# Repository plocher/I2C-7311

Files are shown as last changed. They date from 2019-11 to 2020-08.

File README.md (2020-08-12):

# I2C-7311
## License: CERN Open Hardware Licence v1.2

IO Expander with 4x IO4 connections

### Introduction

This board was originally produced to help me build control panels for
my model railroad - I needed to connect many different buttons, switches
and lights to an Arduino, and also connect the Arduino to a
communications bus (Ethernet, CAN or Loconet), and I couldn\'t find
anything that had both high IO point density AND visual feedback.

I started with a simple I2C based 32-pin Arduino
[IOShield](/pages/IOShield "wikilink") with monitoring LEDs on each pin
(Active-LOW inputs, LED is on when pin is grounded, writing a \"1\" to
the port pulls it to ground). I was aiming to support up to the max I2C
devices that can be used together, with the 8-bit board
[I2C-8574-IO](/pages/I2C-8574-IO "wikilink") (deprecated), that was a total of
8x boards with 128 i/o points.

The 7311 IO expanders used here will support up to 64 boards, with 1024
potential I/O points.

This latest design moves from overly generic and/or overly specialized
designs to a generic design with daughterboards that encapsulate the
appliance-specific buffering and logic. The benefits provided by these
IOB boards include:

-   Improved I/O bank utilization (leftover capacity is now a multiple
    of 4-bit daughtercard instead of 16-bit I2C card\...)
-   Riser height eliminates having to custom cut 3M track
-   Allows deprecation of cabling intensive signal driver IO4 and I2C
    boards
-   Allows custom circuitry to be added to Signal, Detector and Turtle
    drivers

### Cautions

With several hundred IO loads, and up to 256 external breakout devices,
a suitable power supply (or supplies) must be used.

In practice, a 3A 9-12VDC supply a good choice for most small to medium
sized control points.

This supply needs to power the core processor, its direct IO loads, the
I2C expander chain AND provide \~100mA to each IO4 device. Instead of
relying on the Arduino\'s onboard regulated supply (which is only good
for about 100mA itself), each board has its own regulator with a common
supply feed that can handle up to 4A @ 12v. If more power is needed, the
daisy chained power feed thru can be replaced with a per-board
independent supply.

### Specifications

This IO board is based on the MAX7311/12 16 bit IO Expander, with a a
bank of 4x I/O Boards. These IOBs contain buffered LED drivers connected
to LEDs that show the status of the I/O lines in real time. They also
contain the needed circuitry to drive / sense the appliances connected
to them. See

-   [IOB-Inputs](/pages/IOB-Inputs "wikilink") 4x buffered inputs
-   [IOB-Outputs](/pages/IOB-Outputs "wikilink") 4x buffered outputs
-   [IOB-Turtle](/pages/IOB-Turtle "wikilink") 1x buffered output and 3x buffered inputs
-   [IOB-Signal](/pages/IOB-Signal "wikilink") 2x RGB signal head driver (Dark, Stop, Approach, Clear)

Each board provides a latched set of 16x IO points, with each point
being software selectable to be either an input or an output. The
individual points are reasonably protected from the environment, and can
sink 10 mA each (with the MAX7312, they can also drive \~20mA). By using
active low inputs and outputs, the effects of environmental noise are
reduced - remote sensors only need to ground an I/O point to register
activity.

#### Communication Protocol {#communication_protocol}

``` {.cpp}
Simple I2C 16-bit Reads and Writes:
uint16_t I2Cexpander::read7311() {
    uint16_t data = 0;
    Wire.beginTransmission(_i2c_address);
    Wire.write(REGISTER_7311INPUT);
    Wire.endTransmission();
    // Wire.beginTransmission(_i2c_address);
    Wire.requestFrom(_i2c_address, (uint8_t)2);
    if(Wire.available()) {
        data = Wire.read();
    }
    if(Wire.available()) {
        data |= (Wire.read() << 8);
    }
    // Wire.endTransmission();
    return data;
}

void I2Cexpander::write7311(uint16_t data) {
    data = data | _config;
    Wire.beginTransmission(_i2c_address);
    Wire.write(REGISTER_7311OUTPUT);
    Wire.write(0xff & data);  //  low byte
    Wire.write(data >> 8);    //  high byte
    Wire.endTransmission();
}
```

See [I2Cexpander-lib](/pages/I2Cexpander "wikilink") for a more complete interface
library.

#### Addressing

**AD2**|**AD1**|**AD0**|**A6**|**A5**|**A4**|**A3**|**A2**|**A1**|**A0**|**ADDRESS (HEX)**
:-----:|:-----:|:-----:|:-----:|:-----:|:-----:|:-----:|:-----:|:-----:|:-----:|:-----:
GND|SCL|GND|0|0|1|0|0|0|0|0x20
GND|SCL|V+|0|0|1|0|0|0|1|0x22
GND|SDA|GND|0|0|1|0|0|1|0|0x24
GND|SDA|V+|0|0|1|0|0|1|1|0x26
V+|SCL|GND|0|0|1|0|1|0|0|0x28
V+|SCL|V+|0|0|1|0|1|0|1|0x2A
V+|SDA|GND|0|0|1|0|1|1|0|0x2C
V+|SDA|V+|0|0|1|0|1|1|1|0x2E
GND|SCL|SCL|0|0|1|1|0|0|0|0x30
GND|SCL|SDA|0|0|1|1|0|0|1|0x32
GND|SDA|SCL|0|0|1|1|0|1|0|0x34
GND|SDA|SDA|0|0|1|1|0|1|1|0x36
V+|SCL|SCL|0|0|1|1|1|0|0|0x38
V+|SCL|SDA|0|0|1|1|1|0|1|0x3A
V+|SDA|SCL|0|0|1|1|1|1|0|0x3C
V+|SDA|SDA|0|0|1|1|1|1|1|0x3E
GND|GND|GND|0|1|0|0|0|0|0|0x40
GND|GND|V+|0|1|0|0|0|0|1|0x42
GND|V+|GND|0|1|0|0|0|1|0|0x44
GND|V+|V+|0|1|0|0|0|1|1|0x46
V+|GND|GND|0|1|0|0|1|0|0|0x48
V+|GND|V+|0|1|0|0|1|0|1|0x4A
V+|V+|GND|0|1|0|0|1|1|0|0x4C
V+|V+|V+|0|1|0|0|1|1|1|0x4E
GND|GND|SCL|0|1|0|1|0|0|0|0x50
GND|GND|SDA|0|1|0|1|0|0|1|0x52
GND|V+|SCL|0|1|0|1|0|1|0|0x54
GND|V+|SDA|0|1|0|1|0|1|1|0x56
V+|GND|SCL|0|1|0|1|1|0|0|0x58
V+|GND|SDA|0|1|0|1|1|0|1|0x5A
V+|V+|SCL|0|1|0|1|1|1|0|0x5C
V+|V+|SDA|0|1|0|1|1|1|1|0x5E
SCL|SCL|GND|1|0|1|0|0|0|0|0xA0
SCL|SCL|V+|1|0|1|0|0|0|1|0xA2
SCL|SDA|GND|1|0|1|0|0|1|0|0xA4
SCL|SDA|V+|1|0|1|0|0|1|1|0xA6
SDA|SCL|GND|1|0|1|0|1|0|0|0xA8
SDA|SCL|V+|1|0|1|0|1|0|1|0xAA
SDA|SDA|GND|1|0|1|0|1|1|0|0xAC
SDA|SDA|V+|1|0|1|0|1|1|1|0xAE
SCL|SCL|SCL|1|0|1|1|0|0|0|0xB0
SCL|SCL|SDA|1|0|1|1|0|0|1|0xB2
SCL|SDA|SCL|1|0|1|1|0|1|0|0xB4
SCL|SDA|SDA|1|0|1|1|0|1|1|0xB6
SDA|SCL|SCL|1|0|1|1|1|0|0|0xB8
SDA|SCL|SDA|1|0|1|1|1|0|1|0xBA
SDA|SDA|SCL|1|0|1|1|1|1|0|0xBC
SDA|SDA|SDA|1|0|1|1|1|1|1|0xBE
SCL|GND|GND|1|1|0|0|0|0|0|0xC0
SCL|GND|V+|1|1|0|0|0|0|1|0xC2
SCL|V+|GND|1|1|0|0|0|1|0|0xC4
SCL|V+|V+|1|1|0|0|0|1|1|0xC6
SDA|GND|GND|1|1|0|0|1|0|0|0xC8
SDA|GND|V+|1|1|0|0|1|0|1|0xCA
SDA|V+|GND|1|1|0|0|1|1|0|0xCC
SDA|V+|V+|1|1|0|0|1|1|1|0xCE
SCL|GND|SCL|1|1|0|1|0|0|0|0xD0
SCL|GND|SDA|1|1|0|1|0|0|1|0xD2
SCL|V+|SCL|1|1|0|1|0|1|0|0xD4
SCL|V+|SDA|1|1|0|1|0|1|1|0xD6
SDA|GND|SCL|1|1|0|1|1|0|0|0xD8
SDA|GND|SDA|1|1|0|1|1|0|1|0xDA
SDA|V+|SCL|1|1|0|1|1|1|0|0xDC
SDA|V+|SDA|1|1|0|1|1|1|1|0xDE

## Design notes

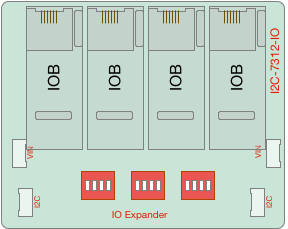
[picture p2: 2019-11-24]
I2C-7311-Graphic.png

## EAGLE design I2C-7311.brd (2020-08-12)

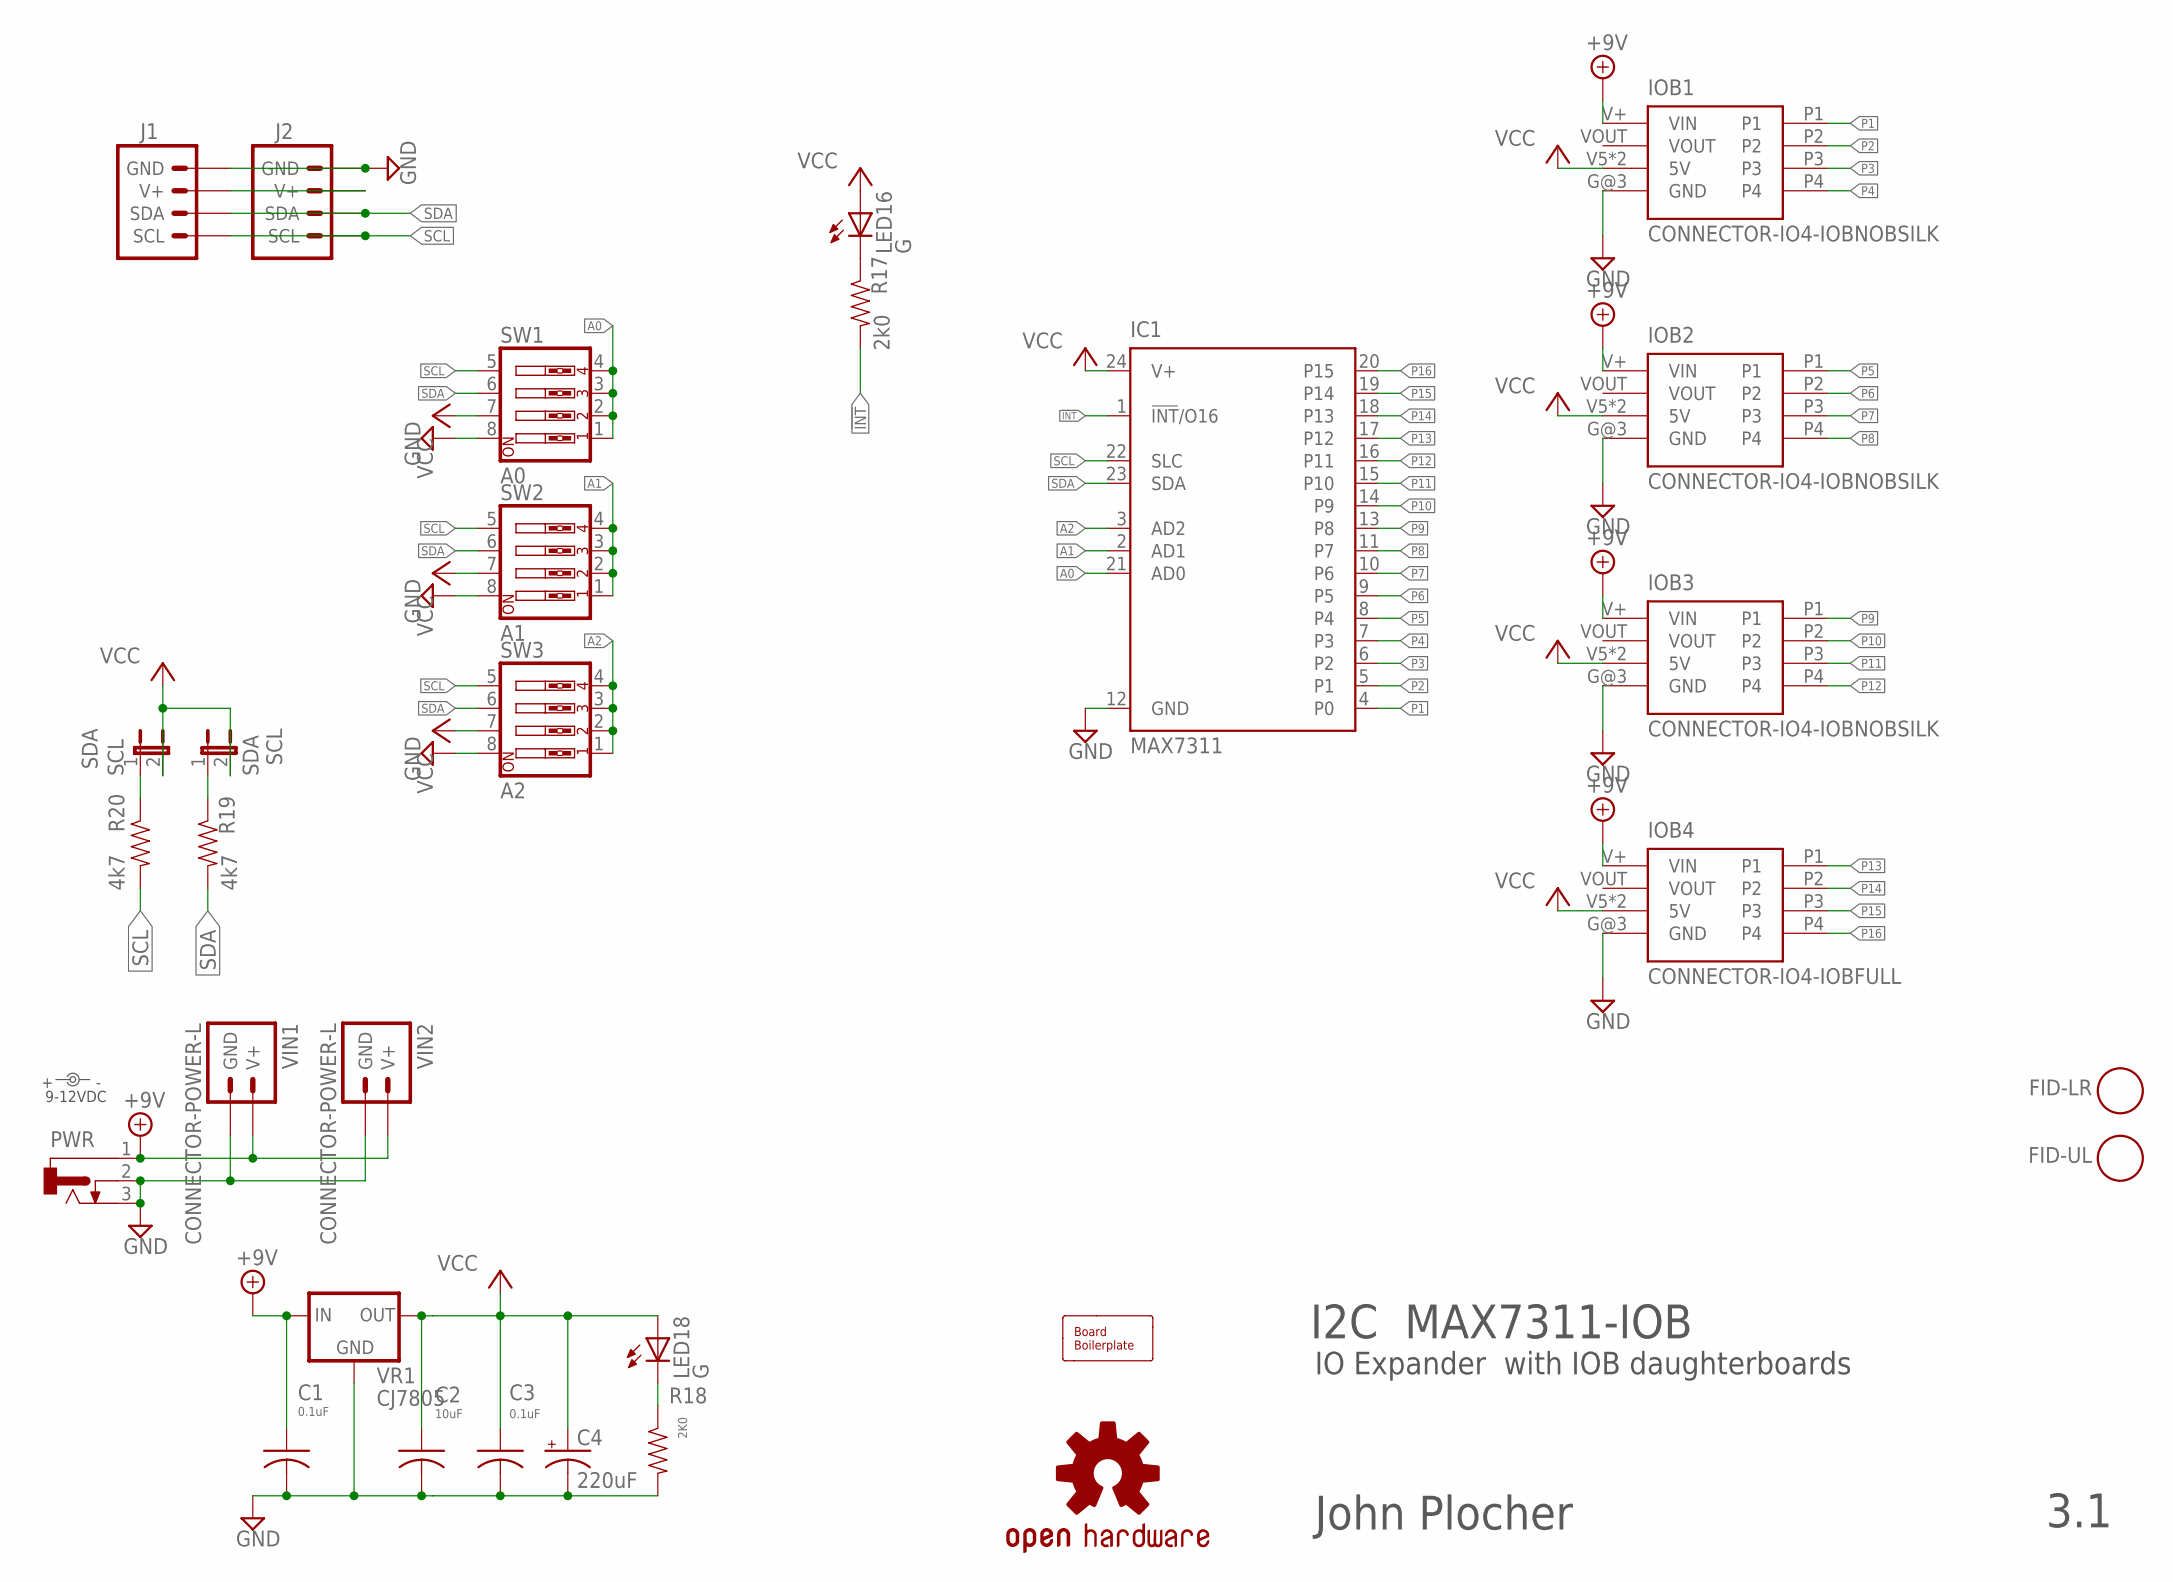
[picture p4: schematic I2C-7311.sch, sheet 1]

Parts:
BOARD1: BOARD80X100-IOB; BOARD-DINRAIL-3.17IN-IOB
C1, C3: 0.1uF; 0805-CAP
C2: 10uF; 0805-CAP
C4: 220uF; 0810-CAP
FID-LR: FIDUCIAL; FIDUCIAL_1MM
FID-UL: FIDUCIAL; FIDUCIAL_1MM
IC1: MAX7311; TSSOP24
IOB1, IOB2, IOB3: CONNECTOR-IO4-IOBNOBSILK; IOB-IO4-NOBOTSILK
IOB4: CONNECTOR-IO4-IOBFULL; IO4-IOB
J1, J2: CONNECTOR-I2CLEFT; I2C-L
LED16, LED18: G; 0603-LED
PWR: CONNECTOR-DC-POWER-RA; DCJ0202
R17: 2k0; 0805-RES
R18: 2K0; 0805-RES
R19, R20: 4k7; 0805-RES
SCL: SDA; 1X02_LOCK
SDA: SCL; 1X02_LOCK
SW1: A0; EDG-04
SW2: A1; EDG-04
SW3: A2; EDG-04
U$1: OSHW-LOGOL; OSHW-LOGO-L
VIN: 9-12VDC; PWR_LABEL
VIN1, VIN2: CONNECTOR-POWER-L; POWER-R2
VR1: CJ7805; TO-252

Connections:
!INT: IC1.1 (!INT!/O16), R17.2
+9V: C1.1, IOB1.V+ (VIN), IOB2.V+ (VIN), IOB3.V+ (VIN), IOB4.V+ (VIN), PWR.1, VIN1.V+, VIN1.V+@1 (V+), VIN1.V+@2 (V+), VIN1.V+@3 (V+), VIN2.V+, VIN2.V+@1 (V+), VIN2.V+@2 (V+), VIN2.V+@3 (V+), VR1.1 (IN)
A0: IC1.21 (AD0), SW1.1, SW1.2, SW1.3, SW1.4
A1: IC1.2 (AD1), SW2.1, SW2.2, SW2.3, SW2.4
A2: IC1.3 (AD2), SW3.1, SW3.2, SW3.3, SW3.4
GND: C1.2, C2.2, C3.2, C4.-, IC1.12 (GND), IOB1.G@3 (GND), IOB2.G@3 (GND), IOB3.G@3 (GND), IOB4.G@3 (GND), J1.GND, J1.GND@1 (GND), J2.GND, J2.GND@1 (GND), PWR.2, PWR.3, R18.2, SW1.8, SW2.8, SW3.8, VIN1.GND, VIN1.GND@1 (GND), VIN1.GND@2 (GND), VIN1.GND@3 (GND), VIN2.GND, VIN2.GND@1 (GND), VIN2.GND@2 (GND), VIN2.GND@3 (GND), VR1.2 (GND); also elsewhere on the board
unnamed: LED18.C, R18.1
unnamed: R19.1, SCL.1
unnamed: R20.1, SDA.1
unnamed: LED16.C, R17.1
P1: IC1.4 (P0), IOB1.P1; also elsewhere on the board
P2: IC1.5 (P1), IOB1.P2; also elsewhere on the board
P3: IC1.6 (P2), IOB1.P3; also elsewhere on the board
P4: IC1.7 (P3), IOB1.P4; also elsewhere on the board
P5: IC1.8 (P4), IOB2.P1; also elsewhere on the board
P6: IC1.9 (P5), IOB2.P2; also elsewhere on the board
P7: IC1.10 (P6), IOB2.P3; also elsewhere on the board
P8: IC1.11 (P7), IOB2.P4; also elsewhere on the board
P9: IC1.13 (P8), IOB3.P1; also elsewhere on the board
P10: IC1.14 (P9), IOB3.P2; also elsewhere on the board
P11: IC1.15 (P10), IOB3.P3; also elsewhere on the board
P12: IC1.16 (P11), IOB3.P4; also elsewhere on the board
P13: IC1.17 (P12), IOB4.P1; also elsewhere on the board
P14: IC1.18 (P13), IOB4.P2; also elsewhere on the board
P15: IC1.19 (P14), IOB4.P3; also elsewhere on the board
P16: IC1.20 (P15), IOB4.P4; also elsewhere on the board
SCL: IC1.22 (SLC), J1.SCL, J1.SCL@1 (SCL), J2.SCL, J2.SCL@1 (SCL), R20.2, SW1.5, SW2.5, SW3.5
SDA: IC1.23 (SDA), J1.SDA, J1.SDA@1 (SDA), J2.SDA, J2.SDA@1 (SDA), R19.2, SW1.6, SW2.6, SW3.6
V+I2C: J1.V+, J1.V+@1 (V+), J2.V+, J2.V+@1 (V+)
VCC: C2.1, C3.1, C4.+, IC1.24 (V+), IOB1.V5 (5V), IOB1.V5@1 (5V), IOB2.V5 (5V), IOB2.V5@1 (5V), IOB3.V5 (5V), IOB3.V5@1 (5V), IOB4.V5 (5V), IOB4.V5@1 (5V), LED16.A, LED18.A, SCL.2, SDA.2, SW1.7, SW2.7, SW3.7, VR1.3 (OUT); also elsewhere on the board

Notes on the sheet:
I2C MAX7311-IOB
IO Expander with IOB daughterboards
John Plocher
3.1

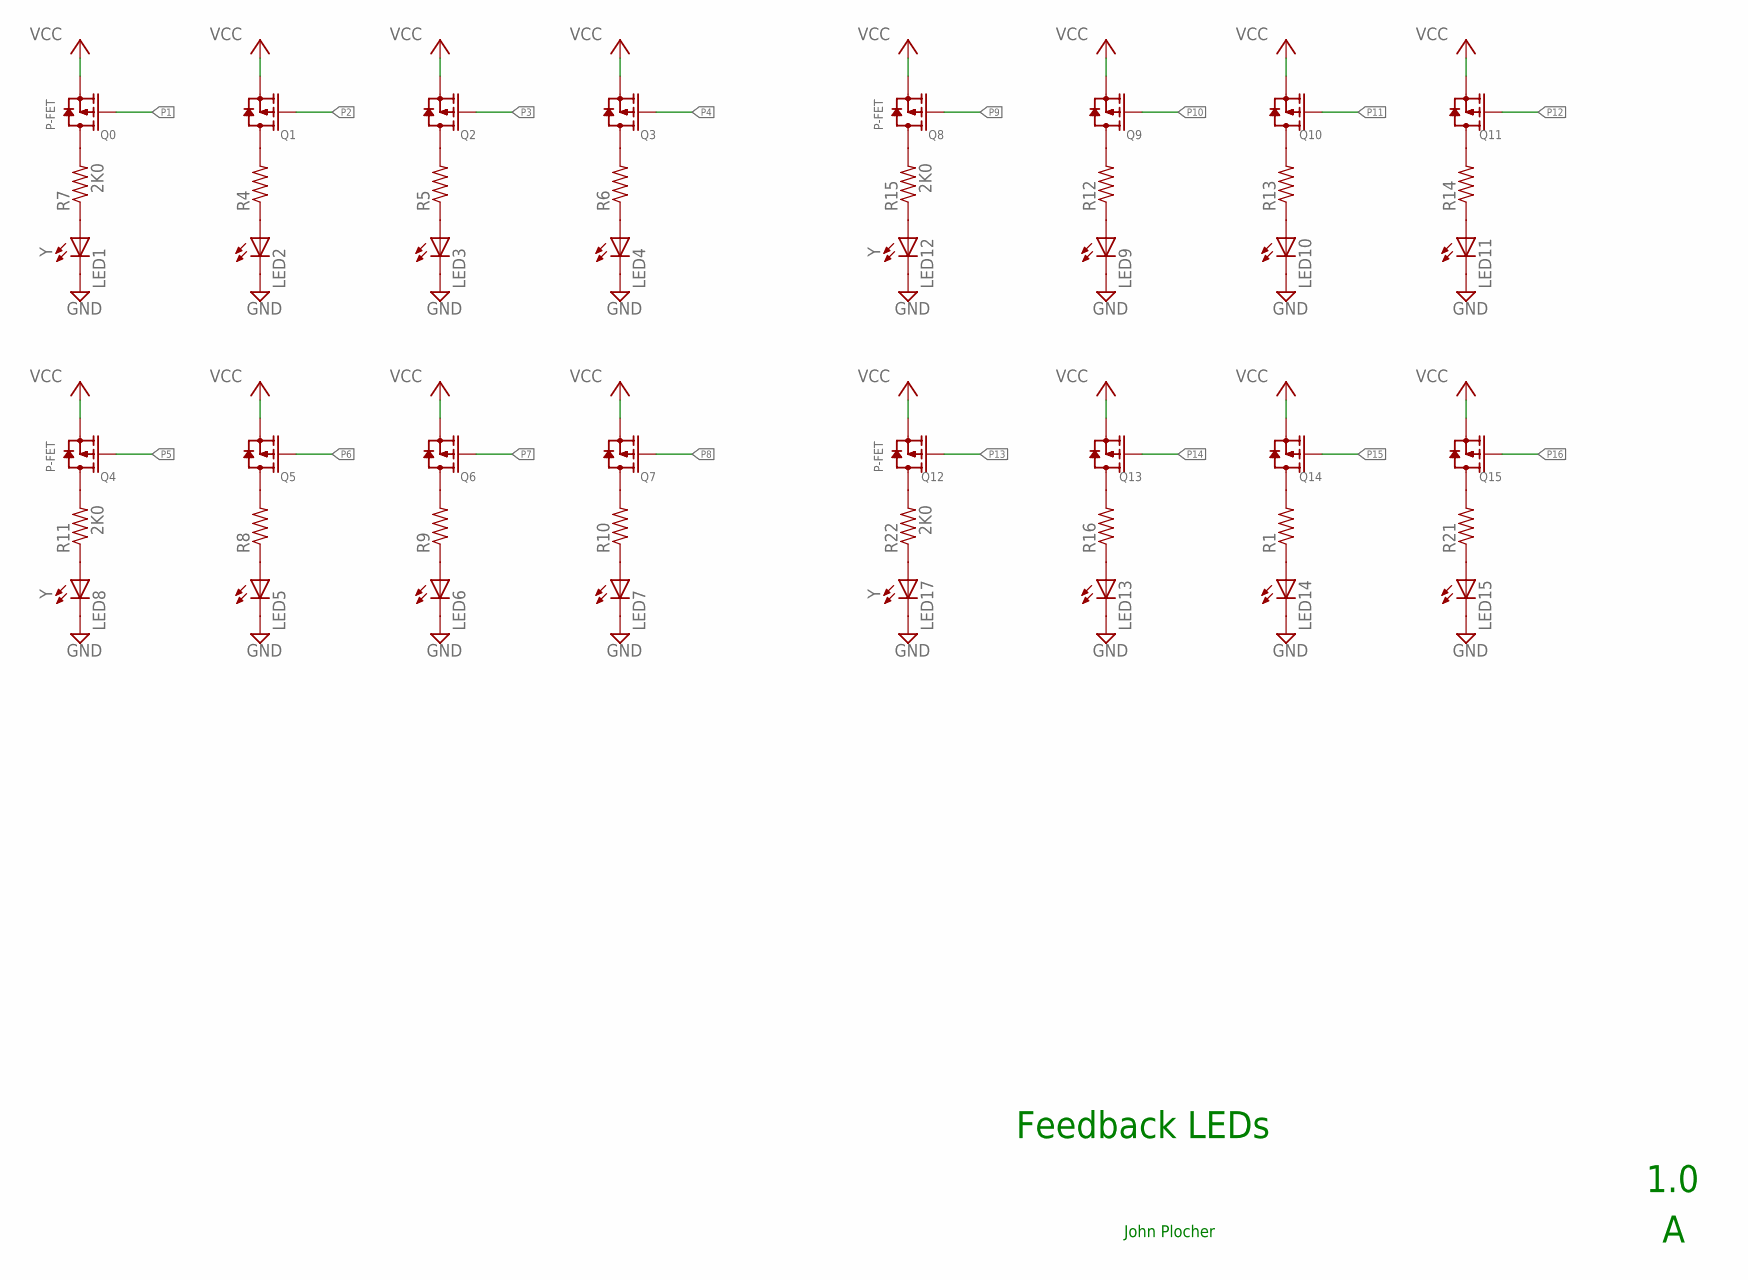
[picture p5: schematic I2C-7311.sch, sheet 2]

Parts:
LED1, LED2, LED3, LED4, LED5, LED6, LED7, LED8, LED9, LED10, LED11, LED12, LED13, LED14, LED15, LED17: Y; 0603-LED
Q0, Q1, Q2, Q3, Q4, Q5, Q6, Q7, Q8, Q9, Q10, Q11, Q12, Q13, Q14, Q15: P-FET; SOT23
R1, R4, R5, R6, R7, R8, R9, R10, R11, R12, R13, R14, R15, R16, R21, R22: 2K0; 0805-RES

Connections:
GND: LED1.C, LED2.C, LED3.C, LED4.C, LED5.C, LED6.C, LED7.C, LED8.C, LED9.C, LED10.C, LED11.C, LED12.C, LED13.C, LED14.C, LED15.C, LED17.C; also elsewhere on the board
unnamed: Q4.3 (D), R11.2
unnamed: Q5.3 (D), R8.2
unnamed: Q6.3 (D), R9.2
unnamed: Q7.3 (D), R10.2
unnamed: LED8.A, R11.1
unnamed: LED5.A, R8.1
unnamed: LED6.A, R9.1
unnamed: LED7.A, R10.1
unnamed: Q8.3 (D), R15.2
unnamed: Q9.3 (D), R12.2
unnamed: Q10.3 (D), R13.2
unnamed: Q11.3 (D), R14.2
unnamed: LED12.A, R15.1
unnamed: LED9.A, R12.1
unnamed: LED10.A, R13.1
unnamed: LED11.A, R14.1
unnamed: Q12.3 (D), R22.2
unnamed: Q13.3 (D), R16.2
unnamed: Q14.3 (D), R1.2
unnamed: Q15.3 (D), R21.2
unnamed: LED17.A, R22.1
unnamed: LED13.A, R16.1
unnamed: LED14.A, R1.1
unnamed: LED15.A, R21.1
unnamed: Q0.3 (D), R7.2
unnamed: Q1.3 (D), R4.2
unnamed: Q2.3 (D), R5.2
unnamed: Q3.3 (D), R6.2
unnamed: LED1.A, R7.1
unnamed: LED2.A, R4.1
unnamed: LED3.A, R5.1
unnamed: LED4.A, R6.1
P1: Q0.1 (G); also elsewhere on the board
P2: Q1.1 (G); also elsewhere on the board
P3: Q2.1 (G); also elsewhere on the board
P4: Q3.1 (G); also elsewhere on the board
P5: Q4.1 (G); also elsewhere on the board
P6: Q5.1 (G); also elsewhere on the board
P7: Q6.1 (G); also elsewhere on the board
P8: Q7.1 (G); also elsewhere on the board
P9: Q8.1 (G); also elsewhere on the board
P10: Q9.1 (G); also elsewhere on the board
P11: Q10.1 (G); also elsewhere on the board
P12: Q11.1 (G); also elsewhere on the board
P13: Q12.1 (G); also elsewhere on the board
P14: Q13.1 (G); also elsewhere on the board
P15: Q14.1 (G); also elsewhere on the board
P16: Q15.1 (G); also elsewhere on the board
VCC: Q0.2 (S), Q1.2 (S), Q2.2 (S), Q3.2 (S), Q4.2 (S), Q5.2 (S), Q6.2 (S), Q7.2 (S), Q8.2 (S), Q9.2 (S), Q10.2 (S), Q11.2 (S), Q12.2 (S), Q13.2 (S), Q14.2 (S), Q15.2 (S); also elsewhere on the board

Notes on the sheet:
Feedback LEDs
1.0
John Plocher

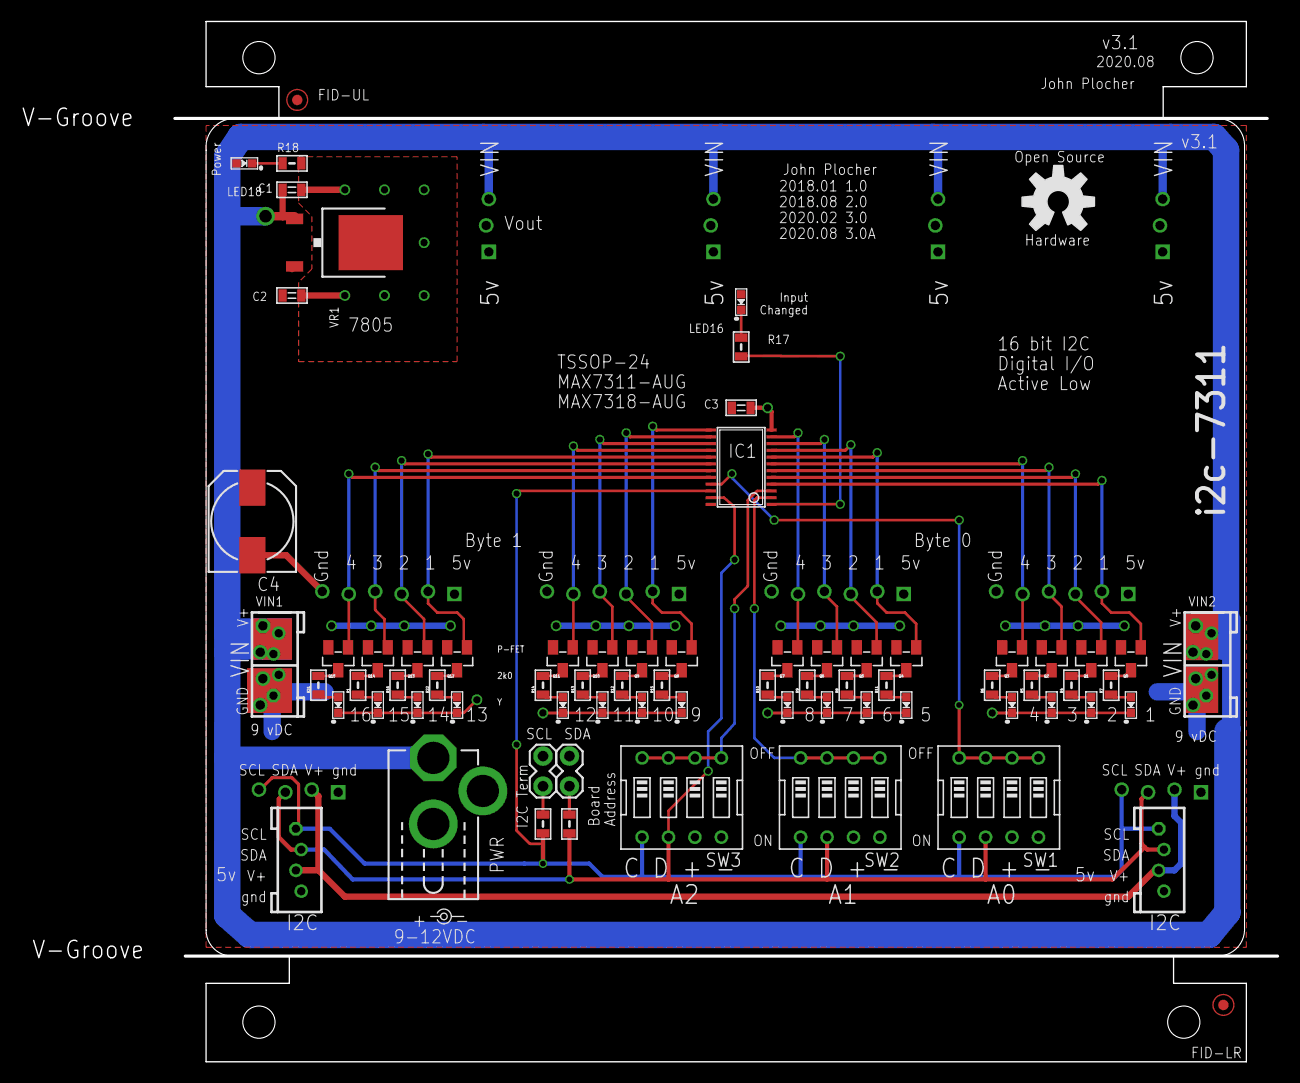
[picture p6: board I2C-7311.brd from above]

Board: 2 copper layers, 106.0 x 100.0 mm, 79 parts (0 on the bottom side), 62 nets.

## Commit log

2020-03-07 3.0 - new IOB design
    [I2C-7311.brd, I2C-7311.sch]
2020-04-19 updated SPCoast lib for IO4-IOB silkscreen
    [I2C-7311.brd, I2C-7311.sch]
2020-08-05 updated SPCoast.lbr: LED, VR, C-POL to match reel orientation
    [I2C-7311.brd, I2C-7311.sch]
2020-08-05 V3.1 again
    [I2C-7311.brd, I2C-7311.sch]
2020-08-12 SPCoast lbr footprint update
    [I2C-7311.brd, I2C-7311.sch]
